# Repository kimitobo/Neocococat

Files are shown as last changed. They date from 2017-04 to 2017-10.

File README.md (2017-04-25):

# Neocococat
Board modification of 8Bitmixtape NEO synthesizer

Neocococat

Neocococat is a board variation from the 8Bitmixtape-NEO circuit and board. 8Bitmixtape is a DIY sound synthesizer electronic circuit using inexpensive and Arduino compatible Attiny85 chip, few very basic components and easy-to-use code uploader using audio jack instead of a USB interface. Please dive in to vast collection of info & material from the following link.

[8Bitmixtape-NEO](http://8bitmixtape.github.io)

Neocococat was designed in Taipei, Dimensionplus April 2017, after Marc Dusseillers 8bitmixtape-NEO DIY pcb etching and (smd) soldering workshop. The circuit is almost identical to 8Bitmixtape-NEO, differences being: 1) only one potentiometer (place for the second pot with the resistors are included on the top of the board) and 2) two NEOpixels instead of 8 as the cat's eyes. All the 8Bitmixtapeneo code should be compatible. I hope I have a chance to contribute also some code derived from the vast collection of fantastic examples at some point. Feel free to copy, remix, do-what-ever-you-want with the board design. Open Source Hardware and coconuts :)

Following information is mainly notes-to-self, but hopefully develops to useful documentation for others.

# V01 : DIY-pcb

## Drawing the circuit in Inkscape

Inkscape PCB drawing

I started with Marc's DIYpcb workshop GärLämpli design assets, which are the used components with their footprings, scaled up to 400% for manual cut&paste circuit design with paper and pen. Instead of drawing by hand, I layed the components in 1:1 to inkscape and started to layout the parts according to the rough idea of the pot as cat's nose, NEOpixels as her eyes, ATtiny as the "brains" and rest around as compact circuit as possible. After the components were roughly in place, I draw the logic lines (nets?) with colour-coded lines for Vcc, Gnd, and signals. After this, I started to draw the copper paths with bezier curves, keeping it organic and trying to include some features of cat's head. But it got pretty corwded and eventually the confined small space dicated the freestylin' quite a bit.

## PCB etching

PCB etching workshop

The copper design was printed with an office laser printer according to what we learned in Marc's workshop and cut out the paper, oiled it (for more translucency in the following exposure), cut piece of ready-to-expose copper PCB, exposed it with Marc's DIY blue-led exposing-station (mirror the image!), spoiled (overexposed) the first trial, doubled the oily paper for better black, exposed for 45sec (do a test exposure), developed the board in 30 degree celcius sodium hydrokside (NAOH) solution until the unexposed part got fixed (rub gently the exposed parts with some gloves) and finally etched the board in +50 degrees celcius sodium peroxodisulfate solution for half an hour or so, until the exposed copper was dissolved (keep it hot, we used larger hot water bath for the etching tray, speeds the process a lot). Finally, the greenish layer of protective coating over the copper design was rubbed away with acetone and the remainings of some dust and garbage copper residue was sanded away.

## Soldering

DIY pcb

Solder the small SMD components first. Especially audio plugs the IC socket and the Pot are so close to resistor and capacitor pads that they should all be in place before soldering the larger components. The (one-sided) board is stable to tape on the table before soldering the power socket and pot. I recommend two intermediate tests while in between the soldering: power circuit + audio code upload and button check.

# V02 : Manufactured board

PCBway boards

## Kicad

After few modification to the Inkscape design, namely bit more room to the pot in the middle and some extra pads for the flipside, the png files were imported to kicad using thehe "logo" method (instead of drawing the board using Kicad schematic & board designer.) This is bit cumbersome process and I will link to some guidelines here later.

[DIY-CAD process](http://www.hackteria.org/wiki/Diy-CAD)

## PCBway

Gerber files were imported from Kicad and zipped and sent to PCBway in Shenzhen for express manufacturing. The 24h option was not available for some reason, so we selected 48h for set of 50 boards, gold immersion on white. 48h + one day for the shipping, a guy with a scooter delivered the boards on Saturday morning. The speed of getting things done in this corner of world is pretty impressive.

## Acknowledgements

This was a learning excercise for DIY board making more than a product design excercise. The shape of the cat's head is a small tribute to my previous visit to Taipei & Dimensionplus for Lemonster workshop in 2015. Big thanks for Marc Dusseiller for very inspiring facilitation and geeking company, and for Escher Tsai and whole Dimensionplus team for heartwarming hosting and hospitality.

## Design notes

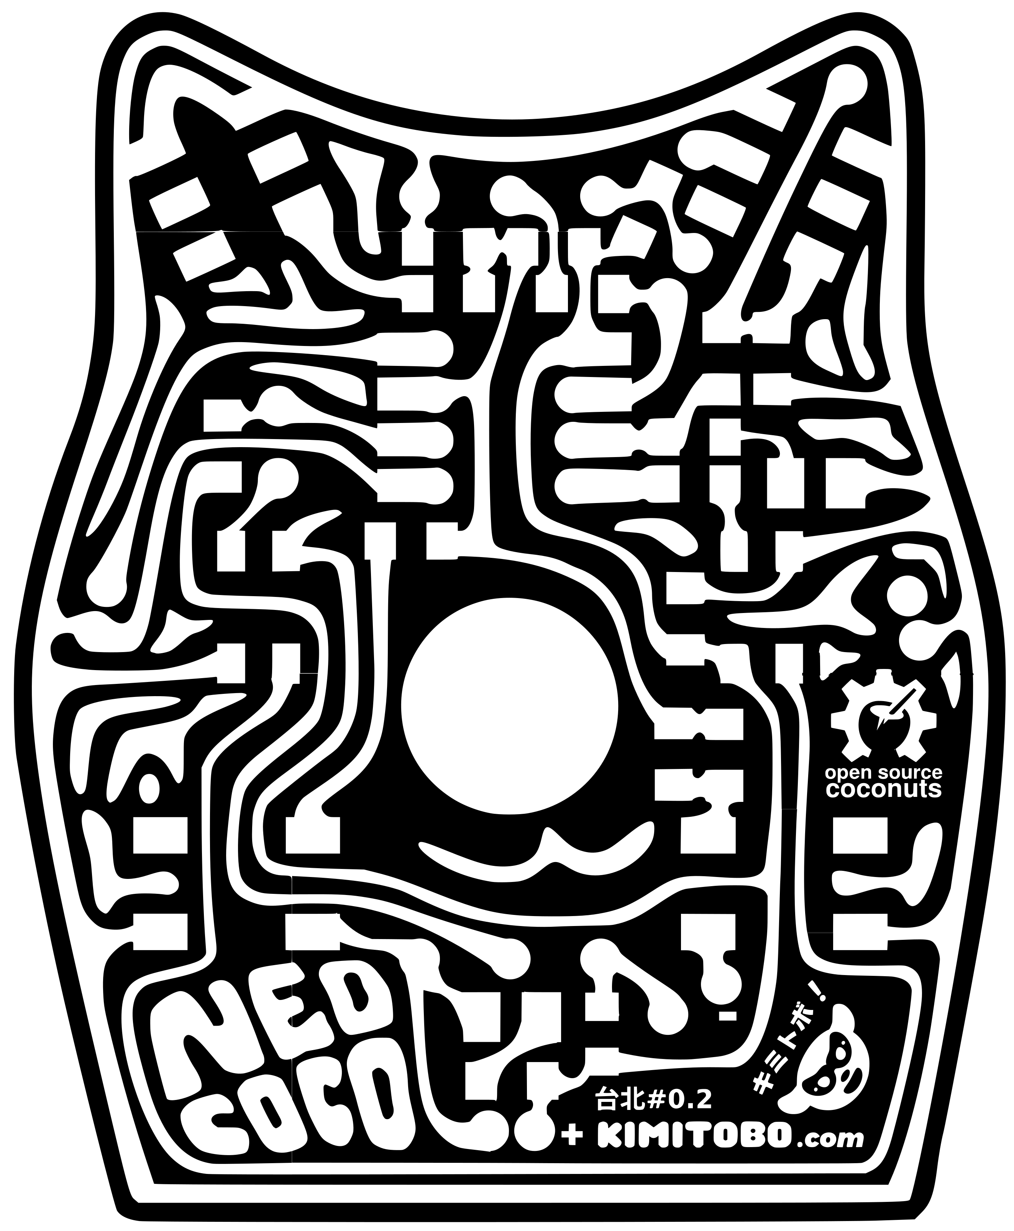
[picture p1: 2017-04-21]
DIY_PCB/Neocococat_Frontmask.png

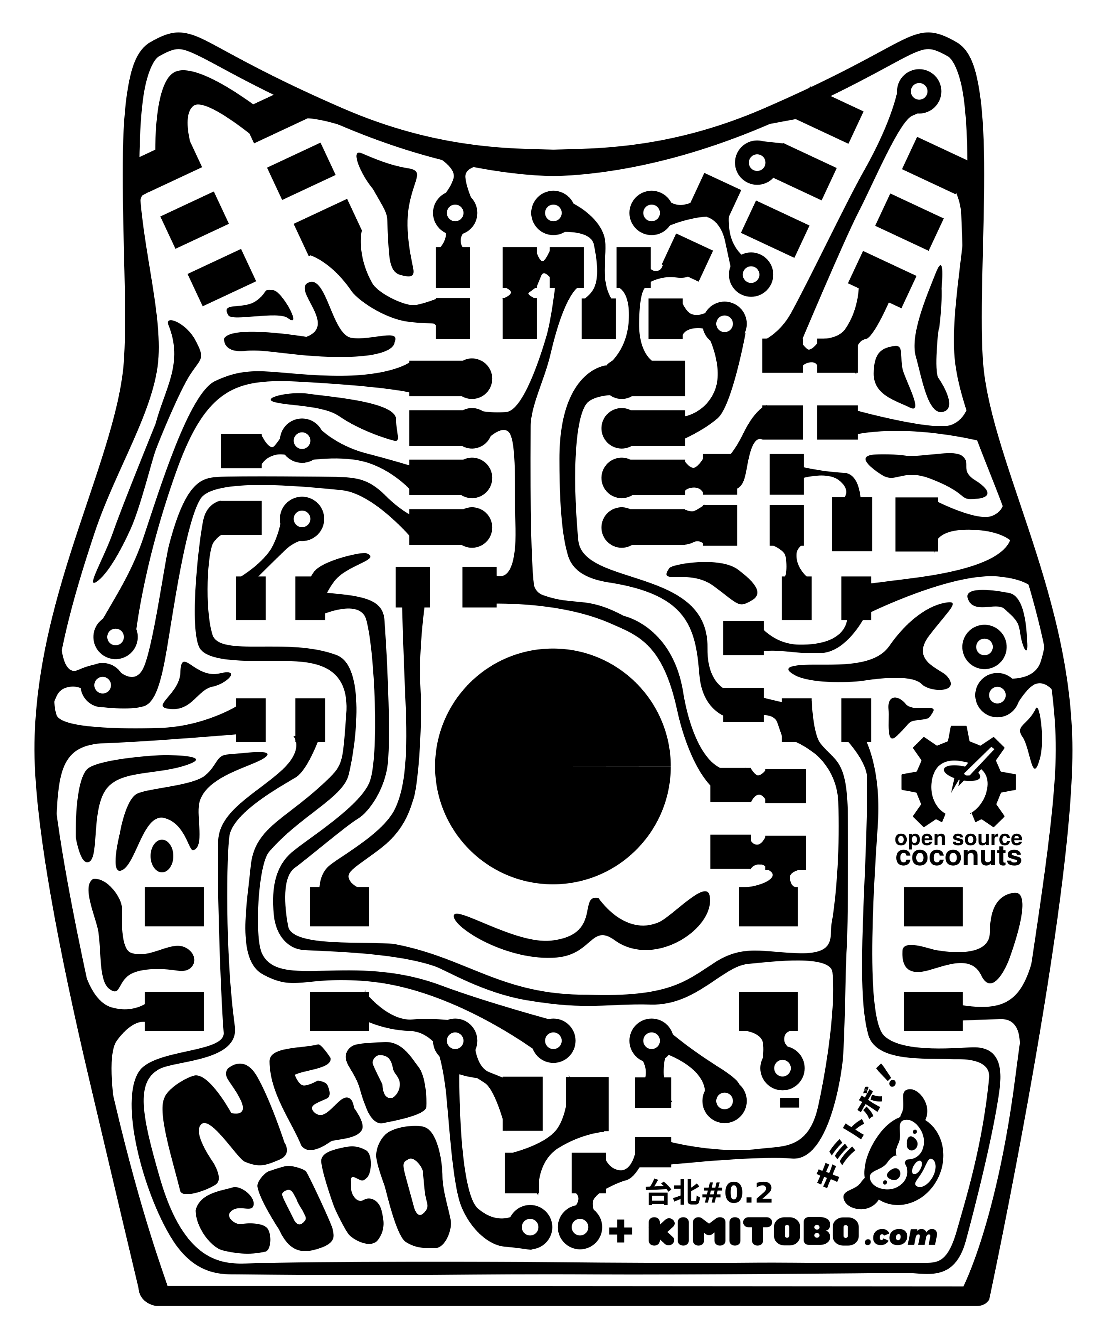
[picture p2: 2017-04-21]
DIY_PCB/Neocococat_Copper_Front_1.png

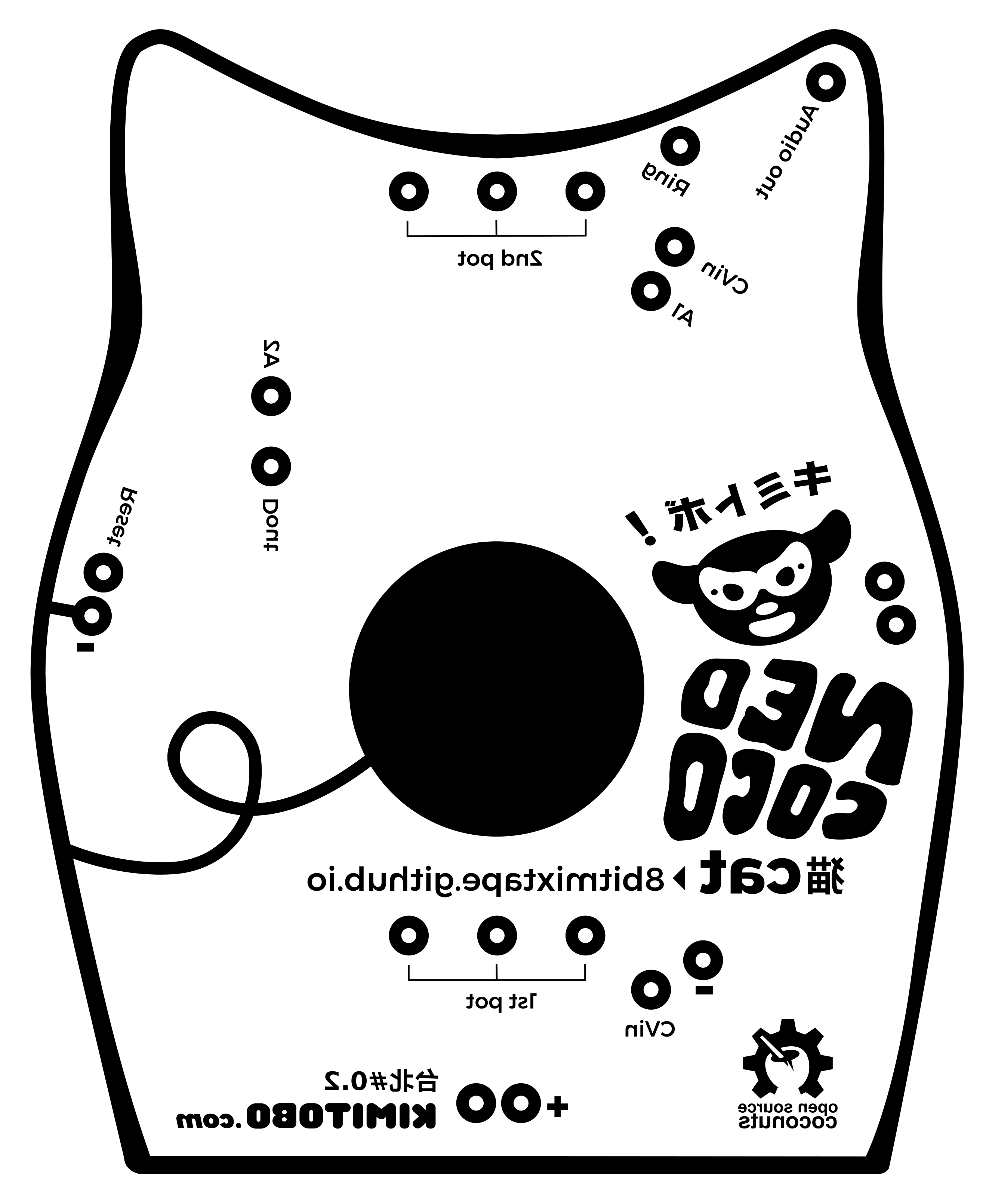
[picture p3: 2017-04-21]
DIY_PCB/Neocococat_Copper_Back_1_mirror.png

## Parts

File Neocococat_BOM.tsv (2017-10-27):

References | Qty | Description | Part Number | Manufacturer | Mouser | Digikey
R1, R2 | 2 | 4.7K 1206 | RC1206FR-074K7L | Yageo | 603-RC1206FR-074K7L | 311-4.70KFRCT-ND
R3 - R6 | 5 | 22K 1206 | RC1206FR-0722KL | Yageo | 603-RC1206FR-0722KL | 311-22.0KFRCT-ND
R7, R8 | 2 | 470 1206 | RC1206FR-07470RL | Yageo | 603-RC1206FR-07470RL | 311-470FRTR-ND
R9, R10 | 2 | 1K 1206 | RC1206FR-071KL (LED) | Yageo | 603-RC1206FR-071KL | 311-1.00KFRCT-ND
C1 - C3 | 3 | 100nF 1206 | C1206C104K5RACTU | KEMET | 80-C1206C104K5R | 399-1249-2-ND
LED1, LED2 | 2 | Indicator LED's | AA3528SURSK | Kingbright | 604-AA3528SURSK | 754-1537-1-ND
NEO | 2 | SK6812 LED (Neopixel) | SK6812 | Adafruit | 485-1655 | 1528-1104-ND
ICS1 | 1 | 8Pin-DIL-Socket | DILB8P-223TLF | Amphenol FCI | 649-DILB8P223TLF | 609-4717-ND
IC1 | 1 | Attiny85 | ATtiny85-20SU | Microchip Technology / Atmel | 556-ATTINY85-20PU | ATTINY85-20PU-ND
B1, B2 | 2 | Control buttons | B3F-1005 | Omron | 653-B3F-1005 | SW793-ND
B3 | 1 | Reset Button | 95C04A3GWRT | Grayhill | 706-95C04A3GWRT | GH7643CT-ND
Jack | 2 | Mini-Jack female 3.5mm | WQP-PJ313D | QingPu Electronics
Pot 1 | 1 | 16mm linear potentiometer | P160KN-0QC15B10K | BI | 858-P160KN-0QC15B10K | 987-1301-ND
Pot 2 (optional) | 1 | 16mm linear potentiometer | P160KN-0QC15B10K | BI | 858-P160KN-0QC15B10K | 987-1301-ND

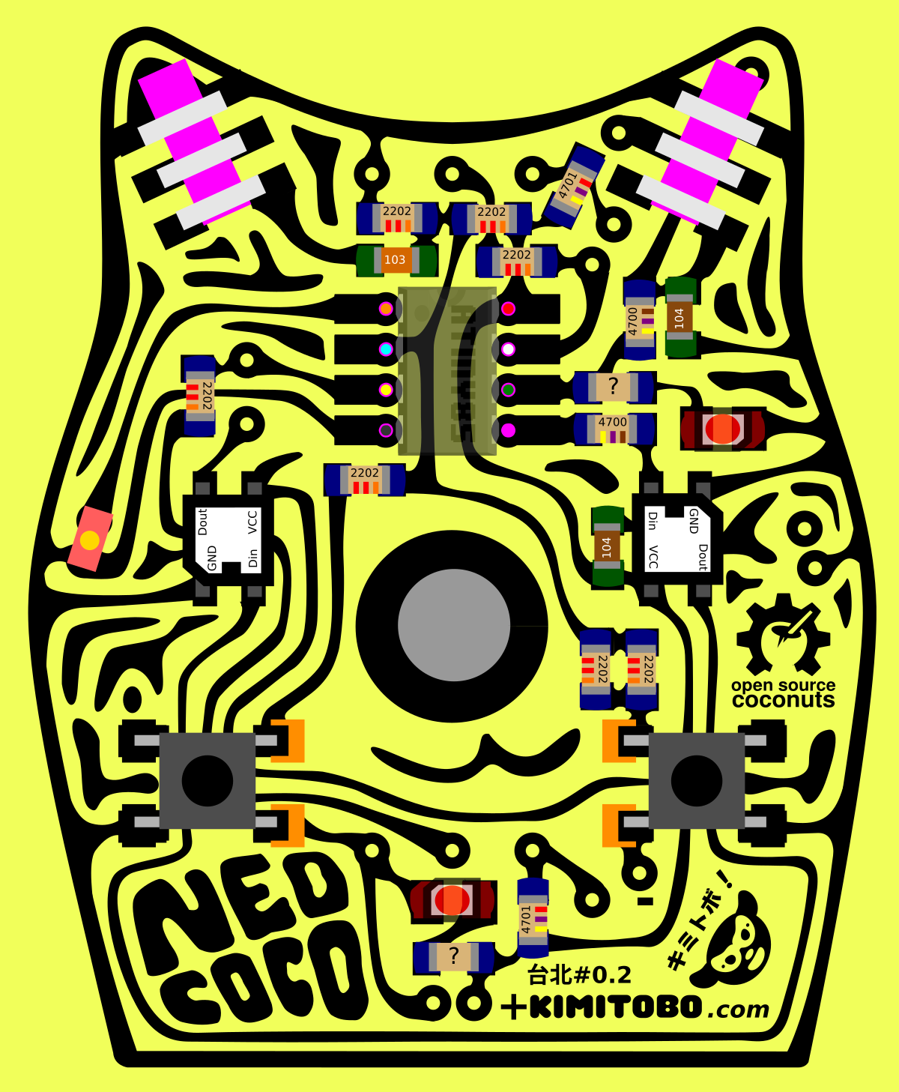
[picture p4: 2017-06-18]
Guides/NeoCoco_parts_placement.png

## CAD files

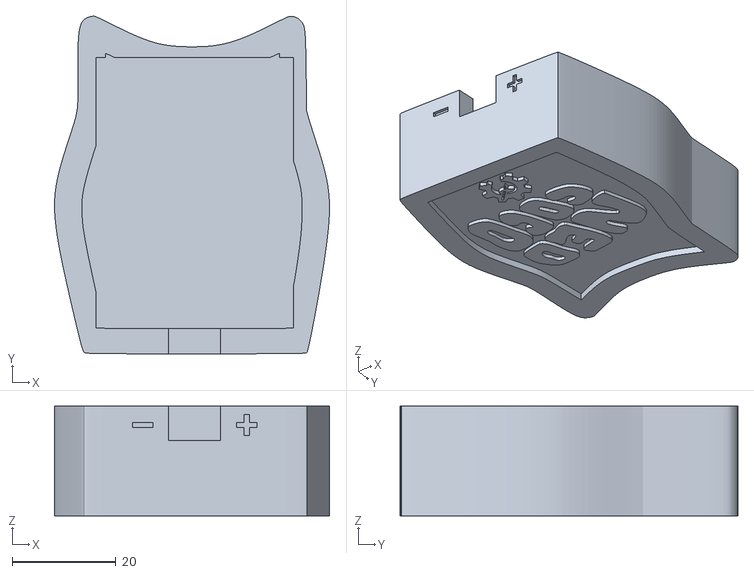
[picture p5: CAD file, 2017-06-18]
3d-files/3D_NeoCoco_Rahmli_Full_01.stl
52.9 x 65.0 x 21.1

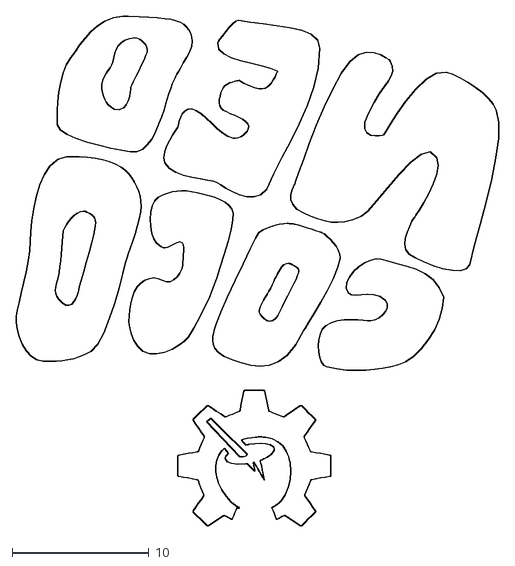
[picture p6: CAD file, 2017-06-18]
3d-files/NeoCoco_logo.dxf
35.3 x 37.3

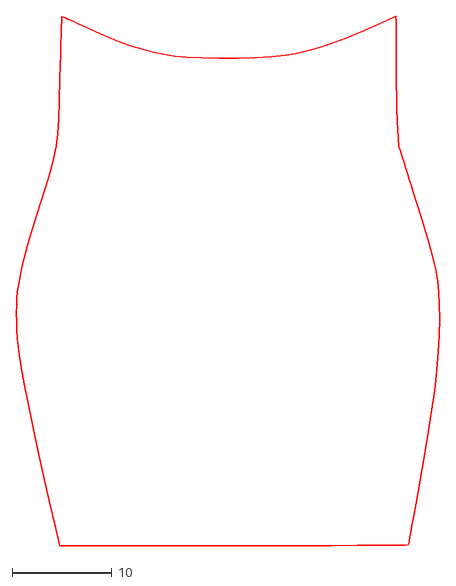
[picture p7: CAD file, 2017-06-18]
3d-files/NeoCoco_hollow.dxf
42.4 x 53.0

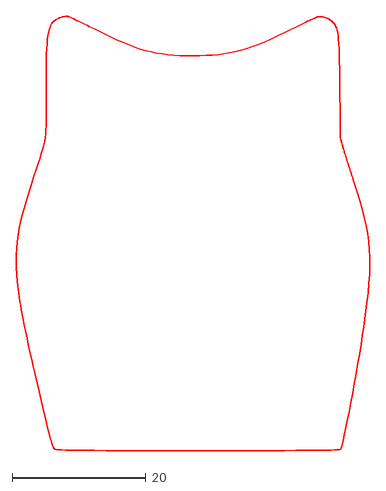
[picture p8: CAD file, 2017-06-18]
3d-files/NeoCoco_frame.dxf
52.9 x 65.0

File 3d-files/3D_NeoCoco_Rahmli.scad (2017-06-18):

    // MixTape 3d Printed Case///////////////////////////

plugHeight = 11; // [6:10]
tapeHeight = 18; //
topThickness = 1.6; 

//PCB();
//parts();

difference(){
    
    FullCase();
    
    // Power signs
    translate([37,0,tapeHeight-2]) cube([4,1.5,1],true);
    translate([37,0,tapeHeight-2]) cube([1,1.5,4],true);
    
    translate([17,0,tapeHeight-2]) cube([4,1.5,1],true); 
}


module FullCase(){
    tapeBody();
    tapeTop();
}

// Modules ///////////////////////////////

module PCB(){
 color("DarkKhaki") 
    translate ([0,0,tapeHeight+1.6]) linear_extrude(height = 1.6, center = false, convexity = 10, twist = 0) import("mixtape_case_3D_bottom.dxf", convexity=3);
 color("Gold") 
     translate ([0,0,tapeHeight+3.2]) linear_extrude(height = 0.2, center = false, convexity = 10, twist = 0) import("mixtape_case_3D_PCB.dxf", convexity=3);
    
 color("DarkKhaki") 
    translate ([0,0,tapeHeight+2*topThickness]) linear_extrude(height = 1.6, center = false, convexity = 10, twist = 0) import("mixtape_case_3D_PCB_TrapezBoard.dxf", convexity=3);
 color("Gold") 
     translate ([0,0,tapeHeight+3*topThickness]) linear_extrude(height = 0.2, center = false, convexity = 10, twist = 0) import("mixtape_case_3D_PCB_TrapezCircuit.dxf", convexity=3);
}

module tapeBody(){ 
  difference(){ 
    color("Deeppink") 
    translate ([0,0,1.6]) linear_extrude(height = tapeHeight, center = false, convexity = 10, twist = 0) import("NeoCoco_frame.dxf", convexity=3);  
    
        translate ([0,0,0.6]) linear_extrude(height = 40, center = false, convexity = 10, twist = 0) import("NeoCoco_hollow.dxf", convexity=3);
    
    //Face holes
    translate([22,0,tapeHeight-5]) cube([10,10,7],false);
      
    translate([8,5,0]) cube([38,52,50],false);

  }
}

module tapeTop(){ 
   difference(){ 
 color("Gold") 
     translate ([0,0,-1.5]) linear_extrude(height = 1.5, center = false, convexity = 10, twist = 0) import("NeoCoco_frame.dxf", convexity=3);
     
   color("Gold") 
     translate ([0,0,-2.5]) linear_extrude(height = 4, center = false, convexity = 10, twist = 0) import("NeoCoco_hollow.dxf", convexity=3);
}
    
  color("Deeppink") 
     translate ([0,0,0]) linear_extrude(height = 1.6, center = false, convexity = 10, twist = 0) import("NeoCoco_frame.dxf", convexity=3);
  color("Gold") 
  translate ([0,0,-1.3]) linear_extrude(height = 0.8, center = false, convexity = 10, twist = 0) import("NeoCoco_logo.dxf", convexity=3); 
}
 

module parts(){
    // IC-Socket
  color("Grey")
      translate([44,22.5,tapeHeight+2*topThickness]) cube([11,13,4],false);
    
  difference(){
  color("Black")
      translate([45,23.5,tapeHeight+2*topThickness]) cube([9,11,7],false);
        
    translate([49.5,34.5,tapeHeight+2*topThickness+6]) cylinder(h=10, r=1.5, center=false, ,$fn=30);
    }
    
    // NEO-Pixels
    for (a = [ 0 : 6.3 : 46 ])
    translate([a,0,0]) NEOpixel();
    
    module NEOpixel(){
    color("White")
      translate([25.2,52.5,tapeHeight+3*topThickness]) cube([5,5,2],false);
        
    color("Deeppink")
      translate([27.7,55,tapeHeight+3*topThickness]) cylinder(h=2.5, r=2, center=false, ,$fn=30);
    }
    
    // Pots
    potentiometer();
    translate ([42,0,0]) potentiometer();
    
    module potentiometer(){
    color("Grey")
      translate([29,29,tapeHeight+2*topThickness]) cylinder(h=10, r=3.5, center=false, ,$fn=30);
    
    color("Deeppink")
        translate([29,29,tapeHeight+2*topThickness+2]) cylinder(h=12, r1=6, r2=4.5, center=false, ,$fn=30);
    }
    
    // Buttons
    button();
    translate ([58,0,0]) button();
    
    module button(){
    color("Grey")
      translate([17.5,9.8,tapeHeight+2*topThickness]) cube([6,6,3],false);
        
    color("Red")
      translate([20.5,12.8,tapeHeight+2*topThickness]) cylinder(h=5, r=1.5, center=false, ,$fn=30);
    }

}

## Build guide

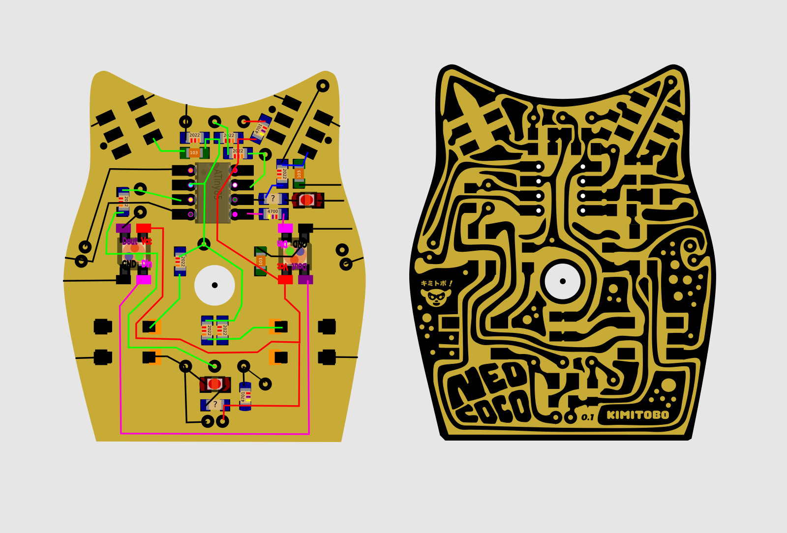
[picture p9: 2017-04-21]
Guides/Neococo_cat_PCBs_wiki.jpg

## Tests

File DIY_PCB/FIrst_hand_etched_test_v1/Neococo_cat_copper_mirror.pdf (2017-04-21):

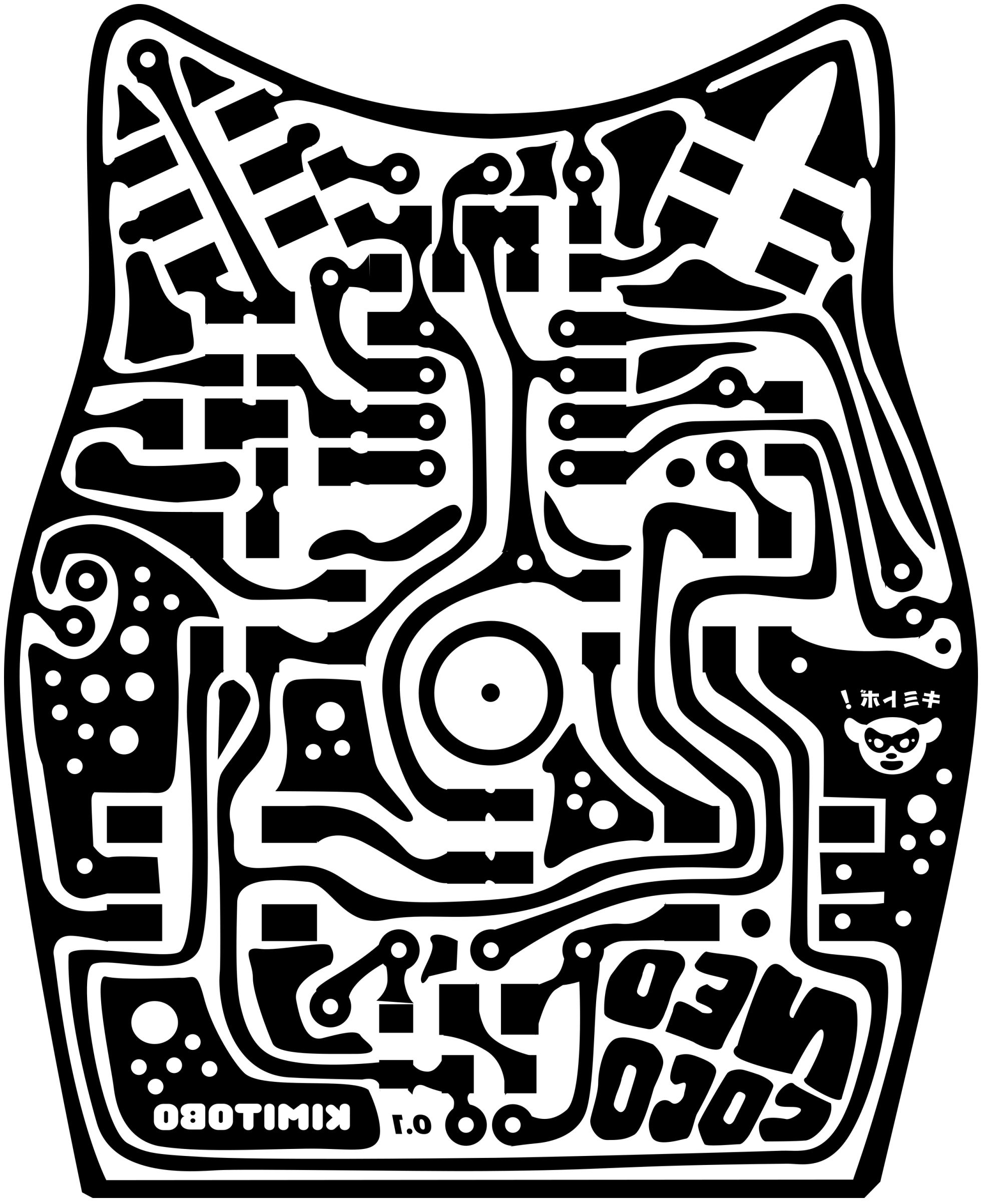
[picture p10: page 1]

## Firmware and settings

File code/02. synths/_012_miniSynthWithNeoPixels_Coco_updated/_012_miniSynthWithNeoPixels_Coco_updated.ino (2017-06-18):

/*************************************************************************************

  Experimental Synth

  Basic sound generator for building modular mixed analog/digital
  synthesizers.

  This was originally made for the chTinySizer an little mixed analog/digital
  synthesizer with 4 ATTINY13 an one Atmega168.

  Today ( 2017 ) the sound could be improved alot by new software techncs.
  Therefore this is a more ore less historic ( 10 years ) version.


*************************************************************************************/

/*************************************************************************************

  Hardware Platform: Attiny85

                                      ATTINY85 Pins
                                      =============

                                             _______
                                            |   U   |
  DEBUGLED / SYNC-OUT             reset/PB5-|       |- VCC
  soundprog / buttons ->  D3/A3         PB3-| ATTINY|- PB2    D2/A1  <- POTI1 / CV-IN
  POTI2 / SYNC-IN ->      D4/A2         PB4-|   85  |- PB1    D1     -> PWM SOUND
                                        GND-|       |- PB0    D0     -> NEOPIXELS
                                            |_______|


*************************************************************************************/

/*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

  20.2.2017  chris, version 1.5    for ATTINY85
  27.2.2017  chris, version 2.0    extended version
  14.6.2017  dusjagr, version 2.1  adding more pre-sets

  C. -H-A-B-E-R-E-R- alias chris

  Please maintain the list of authors.

*************************************************************************************/

#include "Pt1.h"
#include "Oscillator.h"
//#include "neolib.h"

#include <Adafruit_NeoPixel.h>
#ifdef __AVR__
#include <avr/power.h>
#endif

// hardware description / pin connections
#define SPEAKERPIN      1
#define NEOPIXELPIN     0

#define POTI_LEFT      A1
#define POTI_RIGHT     A2
#define BUTTONS_ADC    A3

// hardware calibration
#define Vbutton_left   380
#define Vbutton_right  300
#define Vbutton_both   240
#define Vcc            37 // 3.7 V for LiPo
#define Vdiv           26 // measure max Voltage on Analog In

#define NUMPIXELS      8

Adafruit_NeoPixel pixels = Adafruit_NeoPixel(NUMPIXELS, NEOPIXELPIN, NEO_GRB + NEO_KHZ800);

const int8_t PROGMEM  sintab[] = {
  0 , 3 , 6 , 9 , 12 , 15 , 18 , 21 , 24 , 27 , 30 , 33 , 36 , 39 , 42 , 45 , 48 , 51 , 54 , 57 , 59 , 62 , 65 , 67 , 70 , 73 , 75 , 78 , 80 , 82 , 85 , 87 ,
  89 , 91 , 94 , 96 , 98 , 100 , 102 , 103 , 105 , 107 , 108 , 110 , 112 , 113 , 114 , 116 , 117 , 118 , 119 , 120 , 121 , 122 , 123 , 123 , 124 , 125 , 125 , 126 , 126 , 126 , 126 , 126 ,
  127 , 126 , 126 , 126 , 126 , 126 , 125 , 125 , 124 , 123 , 123 , 122 , 121 , 120 , 119 , 118 , 117 , 116 , 114 , 113 , 112 , 110 , 108 , 107 , 105 , 103 , 102 , 100 , 98 , 96 , 94 , 91 ,
  89 , 87 , 85 , 82 , 80 , 78 , 75 , 73 , 70 , 67 , 65 , 62 , 59 , 57 , 54 , 51 , 48 , 45 , 42 , 39 , 36 , 33 , 30 , 27 , 24 , 21 , 18 , 15 , 12 , 9 , 6 , 3 ,
  0 , -3 , -6 , -9 , -12 , -15 , -18 , -21 , -24 , -27 , -30 , -33 , -36 , -39 , -42 , -45 , -48 , -51 , -54 , -57 , -59 , -62 , -65 , -67 , -70 , -73 , -75 , -78 , -80 , -82 , -85 , -87 ,
  -89 , -91 , -94 , -96 , -98 , -100 , -102 , -103 , -105 , -107 , -108 , -110 , -112 , -113 , -114 , -116 , -117 , -118 , -119 , -120 , -121 , -122 , -123 , -123 , -124 , -125 , -125 , -126 , -126 , -126 , -126 , -126 ,
  -127 , -126 , -126 , -126 , -126 , -126 , -125 , -125 , -124 , -123 , -123 , -122 , -121 , -120 , -119 , -118 , -117 , -116 , -114 , -113 , -112 , -110 , -108 , -107 , -105 , -103 , -102 , -100 , -98 , -96 , -94 , -91 ,
  -89 , -87 , -85 , -82 , -80 , -78 , -75 , -73 , -70 , -67 , -65 , -62 , -59 , -57 , -54 , -51 , -48 , -45 , -42 , -39 , -36 , -33 , -30 , -27 , -24 , -21 , -18 , -15 , -12 , -9 , -6 , -3
};

int8_t sin_int8(uint8_t index)
{
  return pgm_read_byte( &sintab[index] );
}

#define F_CPU 16000000L

volatile uint16_t Freq_coefficient = 1;
volatile uint8_t  Amplitude = 255;

void setFrequency(uint16_t frequency_Hz)
{
  uint16_t temp = (uint32_t) F_CPU / 256 * frequency_Hz / 256 / 128;
  cli();
  Freq_coefficient = temp;
  sei();
}

void setAmplitude(uint8_t amp)
{
  cli();
  Amplitude = amp;
  sei();
}


#define SINUS 0
#define TRIANGLE 1
#define SAWTOOTH 2
#define RECTANGLE 3
#define NOISE 4

uint8_t wavetype = SINUS;
uint8_t RectanglePwmValue = 40;
SIGNAL(TIMER1_COMPA_vect)
{
  static uint8_t x;
  static uint16_t phase1, oldphase;
  static int8_t k, flag = 0;
  static int16_t temp, temp2;
  static uint16_t noise = 0xAA;

  if (flag)
  {
    //Phase VCO
    oldphase = phase1;
    phase1 = phase1 + Freq_coefficient;

    if (wavetype == SINUS)
    {
      temp  = (int8_t) pgm_read_byte ( &sintab[ phase1 >> 8 ] ) ;
    }
    if (wavetype == TRIANGLE)
    {
      x = phase1 >> 8;
      if (x & 0x80) temp = (x ^ 0xFF);
      else temp = x;
      temp = (temp << 1) - 128;
    }

    if (wavetype == RECTANGLE)
    {
      x = phase1 >> 8;
      if (x > RectanglePwmValue)
      {
        temp = 127;
      }
      else temp = -127;
    }
    if (wavetype == SAWTOOTH)
    {
      temp = (phase1 >> 8) - 128;
    }
    if (wavetype == NOISE)
    {
      temp = noise;
      noise = noise << 1;
      temp ^= noise;
      if ( ( temp & 0x4000 ) == 0x4000 )noise |= 1;

      if ((oldphase ^ phase1) & 0x4000)
      {
        temp2 = (noise >> 6) & 0xFF;
      }
      temp = temp2;
    }
  }
  else
  {
    temp = (temp * Amplitude);

    OCR1A = (temp >> 8) + 128;

  }
  flag ^= 0x01;
}


void displayBinrayValue(uint16_t value, uint32_t color)
{
  uint8_t n;
  for (n = 0; n < NUMPIXELS; n++)
  {
    if (value & (1 << n)) pixels.setPixelColor(n, color);
    //else pixels.setPixelColor(n,0); // off
  }
}

void setColorAllPixel(uint32_t color)
{
  uint8_t n;
  for (n = 0; n < NUMPIXELS; n++)
  {
    pixels.setPixelColor(n, color); // off
  }
}

// Input a value 0 to 255 to get a color value.
// The colours are a transition r - g - b - back to r.
uint32_t Wheel(byte WheelPos) {
  WheelPos = 255 - WheelPos;
  if (WheelPos < 85) {
    return pixels.Color(255 - WheelPos * 3, 0, WheelPos * 3);
  }
  if (WheelPos < 170) {
    WheelPos -= 85;
    return pixels.Color(0, WheelPos * 3, 255 - WheelPos * 3);
  }
  WheelPos -= 170;
  return pixels.Color(WheelPos * 3, 255 - WheelPos * 3, 0);
}


void setup ()
{

  cli();

  // Set up Timer/Counter1 31250Hz
  TCCR1 &= ~(7 << CS10); // make sure bits are empty
  TCCR1 |= 1 << CS11;    // set prescaler

  // pulse width modulator A enable
  TCCR1 &= ~(1 << COM1A0);       // make sure register is empty
  TCCR1 |=   1 << COM1A1 ;       // PWM mode: clear the OC1A output line on compare match

  TCCR1 |= 1 << PWM1A;

  TIMSK |= 1 << OCIE1A;          // Enable compare match interrupt for timer 1

  OCR1A = 128;                   // initialize PWM to 50% mean value

  DDRB |= 1 << PB1; // PWM pin as output

  sei();
#if defined (__AVR_ATtiny85__)
  if (F_CPU == 16000000) clock_prescale_set(clock_div_1);
#endif

  pixels.begin(); // This initializes the NeoPixel library.
  setFrequency(440);
  pixels.setBrightness(20);

}

// scaled the adc of the 8BitMixTape voltage divider
// to a return value in range: 0..1023
uint16_t analogReadScaled(uint8_t channel)
{
  uint16_t value = analogRead(channel);
  value = value * Vcc / Vdiv;
  if (value > 1023) value = 1023;
  return value;
}

#define BUTTONS_ADC    A3

/*
  uint8_t getButton()

  return value:
  1: left button pressed
  2: right button pressed
  3: both buttons pressed
  ADC values
  no button:512, left:341, right:248, both:200
*/
uint8_t getButton()
{
  uint8_t button = 0;
  if (analogRead(BUTTONS_ADC) < Vbutton_left) button = 1;
  if (analogRead(BUTTONS_ADC) < Vbutton_right) button = 2;
  if (analogRead(BUTTONS_ADC) < Vbutton_both) button = 3;

  return button;
}

#define LoopTime_ms 5
float AmplitudeModulationFrequency_Hz = 3;
float FrequencyModulationFrequency_Hz = 0.1;

#define POTI_LEFT      A1
#define POTI_RIGHT     A2

uint16_t CycleTimer1_ms = 3000;

Pt1 lp1(0x200);
Pt1 lp2(0x4000);
Oscillator lfo1( LoopTime_ms );
Oscillator lfo2( LoopTime_ms );


void loop()
{
  static uint16_t startTime_ms;

  static int16_t timer1;
  static uint16_t maxFrequency = 3000;

  startTime_ms = millis();
  timer1 = CycleTimer1_ms;

  //lfo1.setFrequency_Hz(10);
  lfo1.setMinMax(10, maxFrequency);
  //lfo1.setWaveform(RECTANGLE);
  //lfo1.setPwmValue(20);

  //lp1.setOutput(255);

  lfo2.setMinMax(0, 255);
  uint8_t selector = 1;
  setColorAllPixel(0); // pixels off

  setColorAllPixel(Wheel(240-(selector*30)));
  pixels.setPixelColor(selector - 1, pixels.Color(0, 100, 0));
  pixels.show(); // This sends the updated pixel color to the hardware.

  uint16_t  mainEnvelope = 255;
  uint8_t singleShot_flag=0;
  while (1)
  {

    // wait for loop cycle
    while ( (uint16_t) millis() - startTime_ms < LoopTime_ms );
    startTime_ms = millis();

    timer1 -= LoopTime_ms;
    if (timer1 <= 0)
    {
      timer1 = CycleTimer1_ms;
      //lp1.setOutput(255);
    }
    volatile static uint16_t v1, v2, v3, v4;
    v3 = analogReadScaled(POTI_RIGHT);
    v4 = analogReadScaled(POTI_LEFT);

    lfo1.setFrequency_mHz(v3 * 60);

    uint16_t lfo2_Hz;
    uint16_t lfo2ModulationMax_Hz;
    uint16_t lfo1Wafeform;
    uint8_t  mainOscillatorWaveType;



    if (selector == 1)
    {
      lfo2_Hz = v4 * 60;
      lfo2.setFrequency_mHz(lfo2_Hz);
    }

    if (selector == 2)
    {
      mainOscillatorWaveType = v4 >> 7;
      if(mainOscillatorWaveType>NOISE)mainOscillatorWaveType=NOISE; 
      wavetype = mainOscillatorWaveType;
    }

    if (selector == 3)
    {
      lfo2ModulationMax_Hz = v4 * 3 + 20;
      lfo1.setMinMax(10, lfo2ModulationMax_Hz);
    }

    if (selector == 4)
    {
      lfo1Wafeform = v4;
      lfo1.setWaveformFine(v4);
    }

    v1 = lfo1.calcNewValue();
    v2 = lfo2.calcNewValue();

    setFrequency(v1);
    setAmplitude((v2 * lp1.filter(mainEnvelope)) >> 8);

    if (getButton() == 1)
    {
      singleShot_flag=true;
      setColorAllPixel(0); // pixels off

      //displayBinrayValue( 0xF, pixels.Color(0, 0, 100));
      pixels.setPixelColor(selector - 1, pixels.Color(200, selector*120, 180-selector*70));
      pixels.show(); // This sends the updated pixel color to the hardware.

      mainEnvelope = 0;
      lp1.setOutput(255);

    }

    if (getButton() == 2)
    {
      mainEnvelope = 255;
      if(!singleShot_flag)      selector++;
      singleShot_flag=false;
      if (selector > 2) selector = 1;

      setColorAllPixel(0); // pixels off

      setColorAllPixel(Wheel(240-((selector-1)*220)));
      pixels.setPixelColor(selector - 1, pixels.Color(0, 190, 0));
      //displayBinrayValue( selector, pixels.Color(0, 100, 0));
      pixels.show(); // This sends the updated pixel color to the hardware.

      while (getButton() != 0);

    }


  }
}

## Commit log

2017-04-21 First file upload
    [PCB.kicad_pcb, PCB.sch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]
2017-04-23 added BOM & documentation
    [Neocococat_BOM.tsv]
2017-04-23 added PCB process link in Readme
2017-05-07 Fixed link in kitnic.yaml
    Currently we need to add the protocol as well.
2017-06-18 adding 3d case
    [3D_NeoCoco_Rahmli.scad, 3D_NeoCoco_Rahmli_Full_01.stl, NeoCoco_frame.dxf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]
2017-06-26 Fixed caps in schematic, added pots to BOM
    [Neocococat_BOM.tsv]
2017-10-27 fixed BOM
    [Neococo_1_BOM.tsv]

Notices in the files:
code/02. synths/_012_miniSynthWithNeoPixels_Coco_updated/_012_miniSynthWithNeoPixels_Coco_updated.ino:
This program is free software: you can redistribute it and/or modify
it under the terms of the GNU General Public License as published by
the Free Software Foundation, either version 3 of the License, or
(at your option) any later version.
